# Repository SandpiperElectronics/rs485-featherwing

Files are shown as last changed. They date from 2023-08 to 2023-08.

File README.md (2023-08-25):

This featherwing PCB allows for long-distance communication between feather microcontrollers. This board implements an RS-485 network with bidirectional communication. RS-485 was selected over other twisted pair protocols due to it having no defined software protocol. 
This featherwing uses a Texas Instruments THVD1424RGTR RS-485 Driver. The THVD1424RGTR driver allows for a single PCB design to implement both endpoints and midpoints in our network. Additionally this board is compatible with the Adafruit Feather microcontroller development board format.

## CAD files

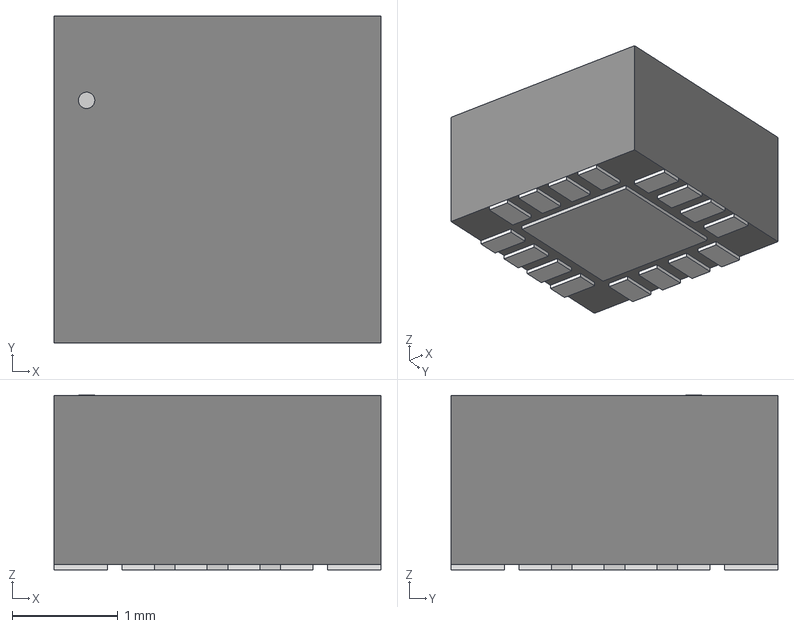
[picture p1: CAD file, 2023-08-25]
3D Models/QFN_24RGTR_TEX.step
3.10 x 3.10 x 1.65 mm

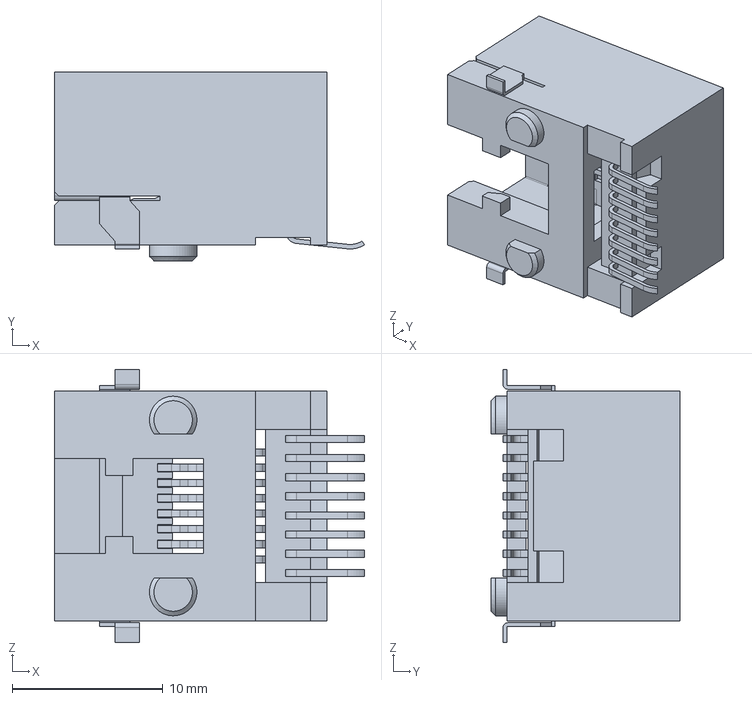
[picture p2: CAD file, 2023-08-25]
3D Models/955406886.stp
20.6 x 12.6 x 18.1 mm

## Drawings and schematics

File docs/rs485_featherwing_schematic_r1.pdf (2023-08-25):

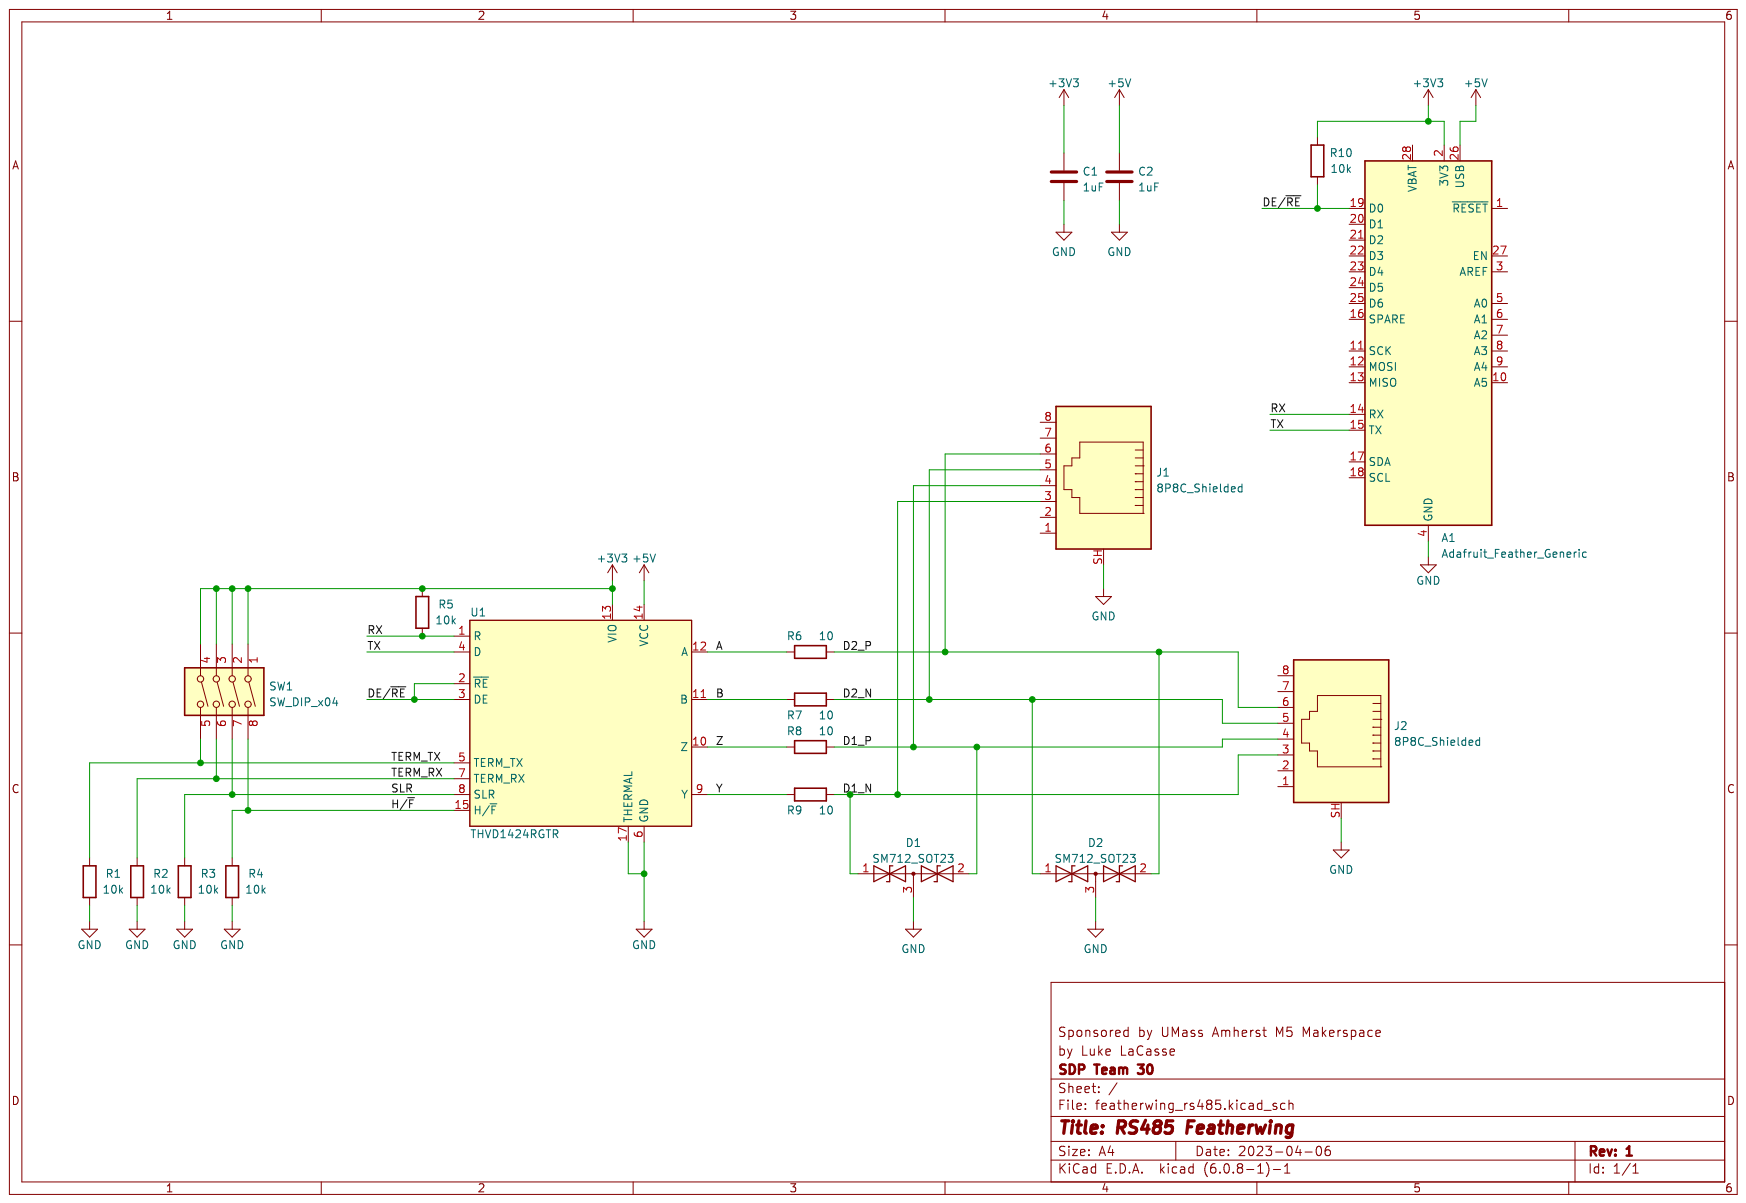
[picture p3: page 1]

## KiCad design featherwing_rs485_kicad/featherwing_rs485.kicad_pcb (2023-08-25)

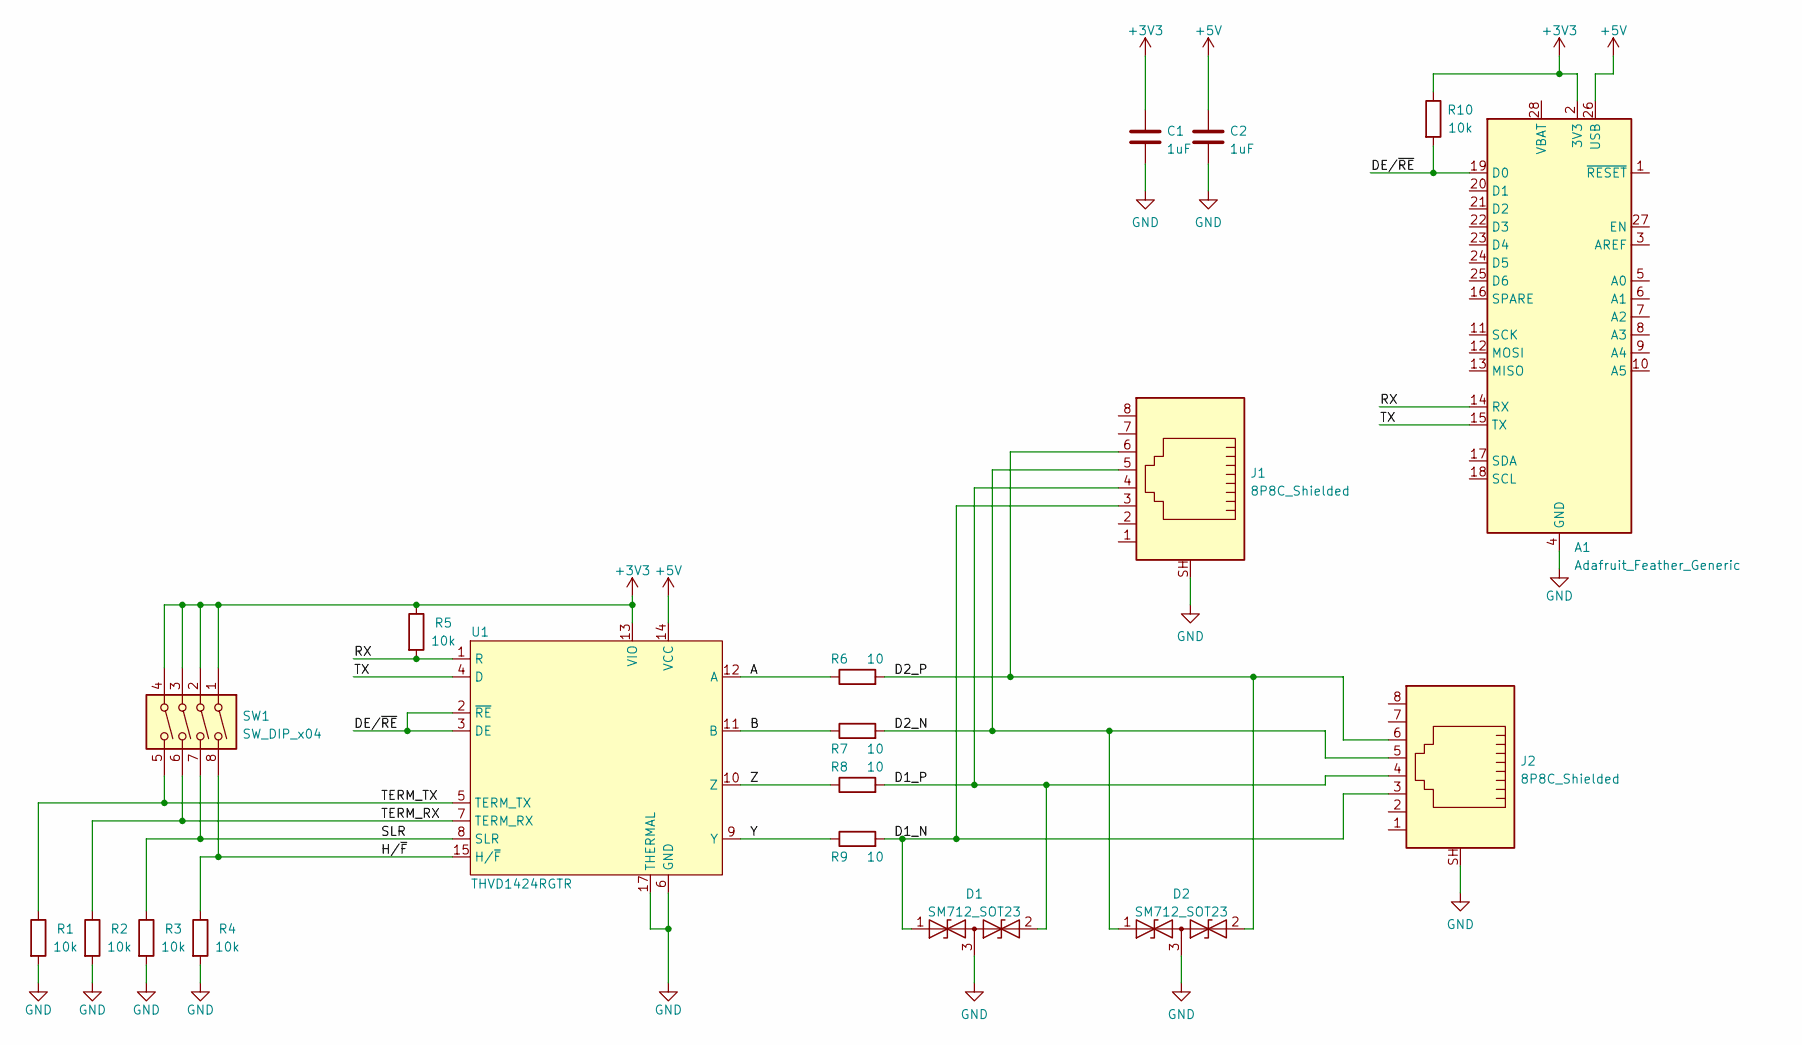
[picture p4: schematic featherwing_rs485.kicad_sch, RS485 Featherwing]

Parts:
A1: Adafruit_Feather_Generic; Adafruit_Feather
C1, C2: 1uF; R_0603_1608Metric
D1, D2: SM712_SOT23; SOT-23
J1, J2: 8P8C_Shielded; 0955406888-MOLEX
R1, R2, R3, R4, R5, R10: 10k; R_0603_1608Metric
R6, R7, R8, R9: 10; R_0603_1608Metric
SW1: SW_DIP_x04; SW_DIP_SPSTx04_Slide_6.7x11.72mm_W6.73mm_P2.54mm_LowProfile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
U1: THVD1424RGTR; VQFN-16-1EP_3x3mm_P0.5mm_EP1.8x1.8mm_ThermalVias

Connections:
+3V3: A1.2 (3V3), C1.1, R5.1, R10.1, SW1.1, SW1.2, SW1.3, SW1.4, U1.13 (VIO)
+5V: A1.26 (USB), C2.1, U1.14 (VCC)
/A: R6.1, U1.12 (A)
/B: R7.1, U1.11 (B)
/D1_N: D1.1 (A1), J1.3, J2.3, R9.2
/D1_P: D1.2 (A2), J1.4, J2.4, R8.2
/D2_N: D2.1 (A1), J1.5, J2.5, R7.2
/D2_P: D2.2 (A2), J1.6, J2.6, R6.2
/DE/~RE: A1.19 (D0), R10.2, U1.2 (~RE), U1.3 (DE)
/H/~F: R4.1, SW1.8, U1.15 (H/~F)
/RX: A1.14 (RX), R5.2, U1.1 (R)
/SLR: R3.1, SW1.7, U1.8 (SLR)
/TERM_RX: R2.1, SW1.6, U1.7 (TERM_RX)
/TERM_TX: R1.1, SW1.5, U1.5 (TERM_TX)
/TX: A1.15 (TX), U1.4 (D)
/Y: R9.1, U1.9 (Y)
/Z: R8.1, U1.10 (Z)
GND: A1.4 (GND), C1.2, C2.2, D1.3 (common), D2.3 (common), J1.SH, J2.SH, R1.2, R2.2, R3.2, R4.2, U1.6 (GND), U1.17 (THERMAL)

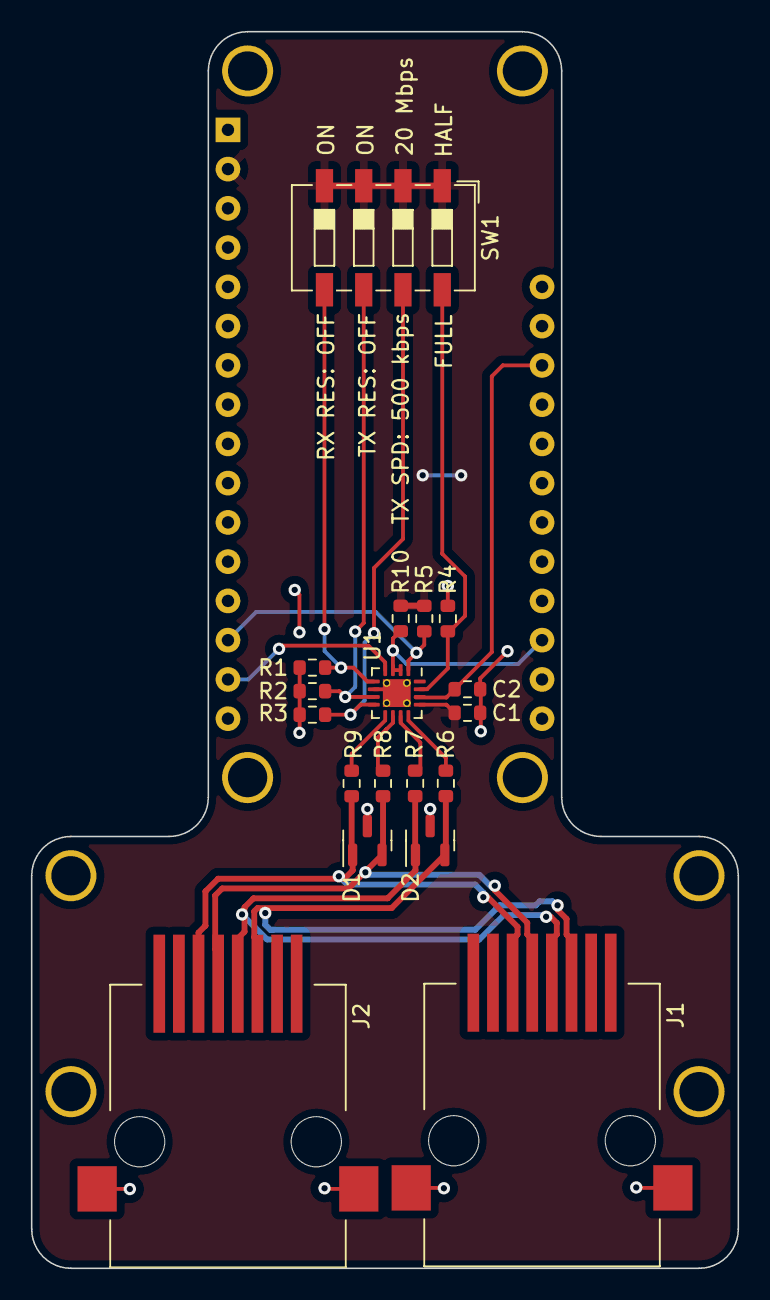
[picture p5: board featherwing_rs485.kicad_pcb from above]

Board: 2 copper layers, 45.7 x 80.0 mm, 19 parts (0 on the bottom side), 18 nets.
